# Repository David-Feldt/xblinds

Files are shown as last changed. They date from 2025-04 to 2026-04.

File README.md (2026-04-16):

# xBlinds - Smart Motorized Blinds Controller

An open-source smart blinds controller built on the ESP8266. Control your roller blinds via a web interface, scheduled alarms, rotary encoder, or Home Assistant integration.

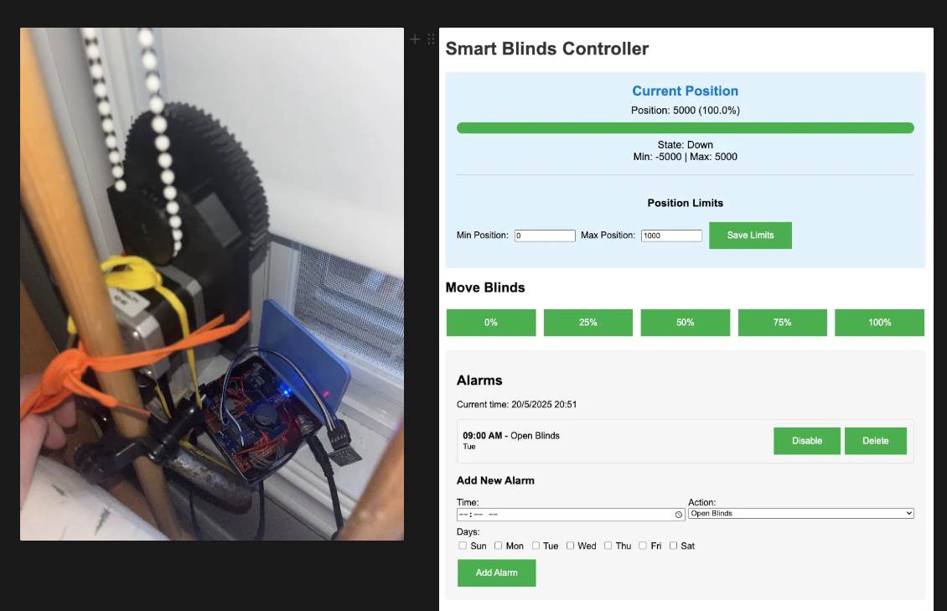
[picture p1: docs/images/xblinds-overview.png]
xBlinds Overview


## Features

- **Web Interface** - Responsive UI with real-time position display, preset buttons (0/25/50/75/100%), and position limit configuration
- **Scheduled Alarms** - Set up to 10 alarms to automatically open or close blinds on specific days and times
- **Rotary Encoder** - Manual control directly on the unit with push-button support
- **NTP Time Sync** - Automatic clock synchronization from the internet
- **WiFi with AP Fallback** - Connects to your home WiFi, falls back to an access point if unavailable
- **mDNS** - Access the controller at `http://blinds.local`
- **EEPROM Persistence** - Saves position, limits, and alarms across reboots
- **ESPHome Support** - Alternative ESPHome configurations for Home Assistant integration

## Hardware

| Component | Description |
|---|---|
| **Microcontroller** | ESP8266 D1 Mini (AZDelivery or similar) |
| **Stepper Motor** | 28BYJ-48 5V with ULN2003 driver board |
| **RTC Module** | DS3231 I2C real-time clock with battery backup |
| **Rotary Encoder** | With push button (KY-040 or similar) |
| **Power Supply** | 5V 2A (do **not** power via USB alone) |

> Alternative: NEMA17 stepper motor with A4988 driver (see `software/nema17/`)

### Wiring

| ESP8266 Pin | Connection |
|---|---|
| D1 | Encoder DT |
| D2 | Encoder CLK |
| D3 | I2C SCL (RTC) |
| D4 | I2C SDA (RTC) |
| D5 | Stepper DIR |
| D6 | Stepper STEP |
| D7 | Encoder Button |

## Getting Started

### 1. Configure WiFi

Edit `software/blinds_controller/blinds_controller.ino` and set your WiFi credentials:

```cpp
const char* ssid = "YOUR_WIFI_SSID";
const char* password = "YOUR_WIFI_PASSWORD";
```

### 2. Build and Upload

Using Arduino CLI:

```bash
# Compile
arduino-cli compile --fqbn esp8266:esp8266:d1_mini software/blinds_controller/blinds_controller.ino

# Upload (adjust port for your system)
arduino-cli upload -p /dev/cu.usbserial-110 --fqbn esp8266:esp8266:d1_mini software/blinds_controller/blinds_controller.ino

# Monitor serial output
arduino-cli monitor -p /dev/cu.usbserial-110 -c baudrate=115200
```

Or use the build script:

```bash
cd software
./build.sh -a  # Build, upload, and monitor
```

### 3. Connect

Once running, the controller is accessible at:
- `http://blinds.local` (via mDNS)
- The IP address shown in the serial monitor

If WiFi connection fails, it creates an open access point with SSID `blinds`.

### 4. Set Position Limits

Use the web UI to configure the min and max positions for your blinds, then save. The controller remembers these across reboots.

## API Endpoints

| Endpoint | Method | Description |
|---|---|---|
| `/` | GET | Web interface |
| `/api/status` | GET | Position, state, limits, network info |
| `/api/moveto?percentage=N` | GET | Move to position (0-100%) |
| `/api/alarms` | GET | List all alarms |
| `/api/alarms` | POST | Add, delete, or toggle alarms |
| `/api/time` | GET/POST | Get or set RTC time |
| `/api/sync-ntp` | GET | Sync clock from NTP |
| `/api/setup?action=X` | GET | Setup mode (start/stop/save/status) |

## ESPHome Alternative

If you prefer ESPHome over custom firmware, configurations are available in:
- `software/blinds.yaml` - Basic ESPHome config
- `esphome/stepper.yaml` - Stepper motor config with Home Assistant integration

## 3D Printed Parts

STL and 3MF files for the enclosure and gears are in the `mechanical/` directory. Designed in FreeCAD.

## Project Structure

```
xblinds/
├── software/
│   ├── blinds_controller/    # Main firmware (recommended)
│   ├── stepper/              # AccelStepper variant
│   ├── nema17/               # NEMA17 motor variant
│   ├── demo_step/            # Basic stepper test
│   ├── blinds.yaml           # ESPHome config
│   └── build.sh              # Build/upload script
├── esphome/                  # ESPHome configurations
├── mechanical/               # 3D models (STL, 3MF, STEP)
└── examples/                 # Reference projects and configs
```

## Dependencies

- [ESP8266 Arduino Core](https://github.com/esp8266/Arduino)
- [RTClib](https://github.com/adafruit/RTClib) - DS3231 RTC support
- [Encoder](https://github.com/PaulStoffregen/Encoder) - Rotary encoder library
- [NTPClient](https://github.com/arduino-libraries/NTPClient) - NTP time sync

## License

This project is open source. Original xBlinds concept from [Thingiverse](https://www.thingiverse.com/thing:4792584).

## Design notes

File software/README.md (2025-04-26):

Compile
arduino-cli compile --fqbn esp8266:esp8266:d1_mini stepper.ino

Upload to ESP8266
arduino-cli upload -p /dev/cu.usbserial-110 --fqbn esp8266:esp8266:d1_mini stepper.ino

Monitor
arduino-cli monitor -p /dev/cu.usbserial-110 -c baudrate=115200

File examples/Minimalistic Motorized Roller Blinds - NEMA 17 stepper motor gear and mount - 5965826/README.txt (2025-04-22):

Minimalistic Motorized Roller Blinds - NEMA 17 stepper motor gear and mount by lushey on Thingiverse: https://www.thingiverse.com/thing:5965826

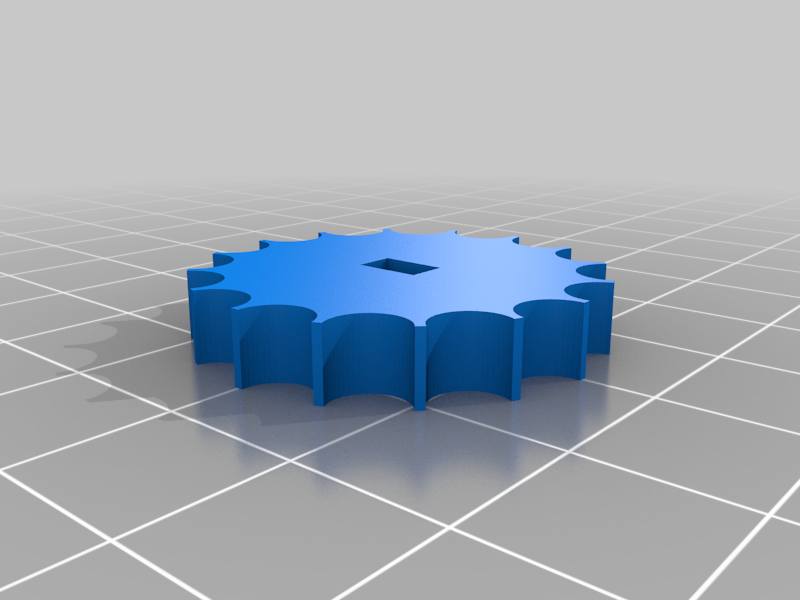
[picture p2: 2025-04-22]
examples/Blinds Smart Home Automation - 4966303/images/Smart_Home_-_Gear.png

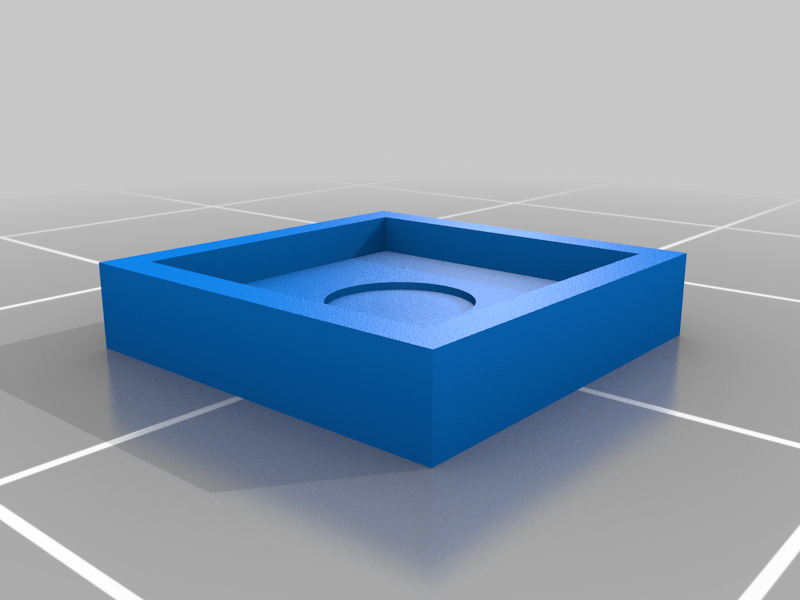
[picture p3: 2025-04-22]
examples/xBlinds - 4792584/images/Tactile_Button_Top.png

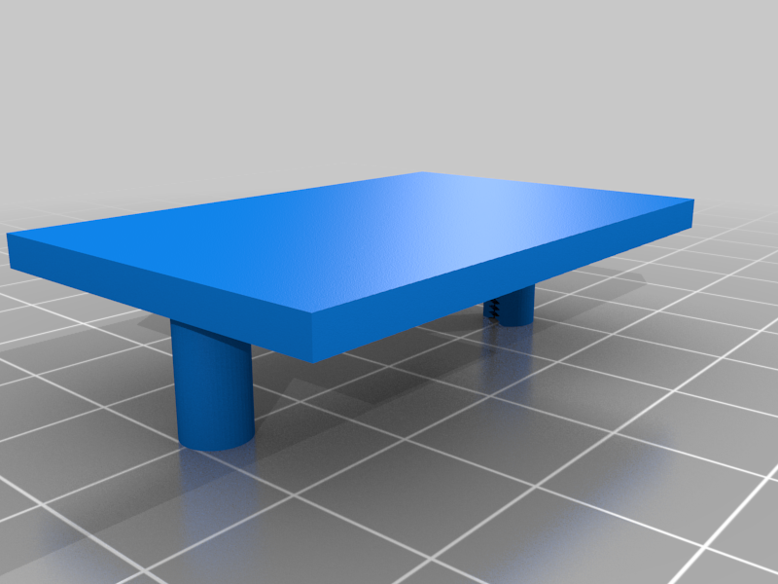
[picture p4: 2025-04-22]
examples/Blinds Smart Home Automation - 4966303/images/Smart_Home_-_Gear_Holder_2-2.png

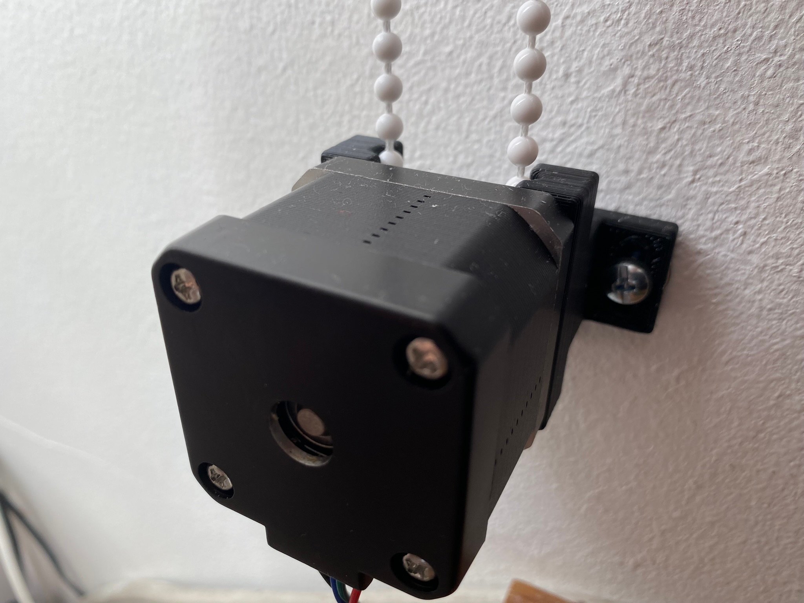
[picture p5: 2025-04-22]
examples/Minimalistic Motorized Roller Blinds - NEMA 17 stepper motor gear and mount - 5965826/images/cdb99ff9-2e51-49e6-be68-403bfa26b47f.JPEG

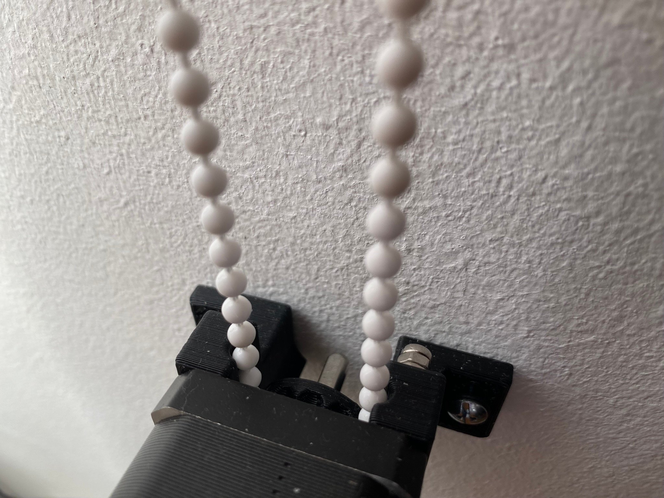
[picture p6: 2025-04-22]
examples/Minimalistic Motorized Roller Blinds - NEMA 17 stepper motor gear and mount - 5965826/images/24057941-1a3e-4d87-ac36-347bbf882cc1.JPEG

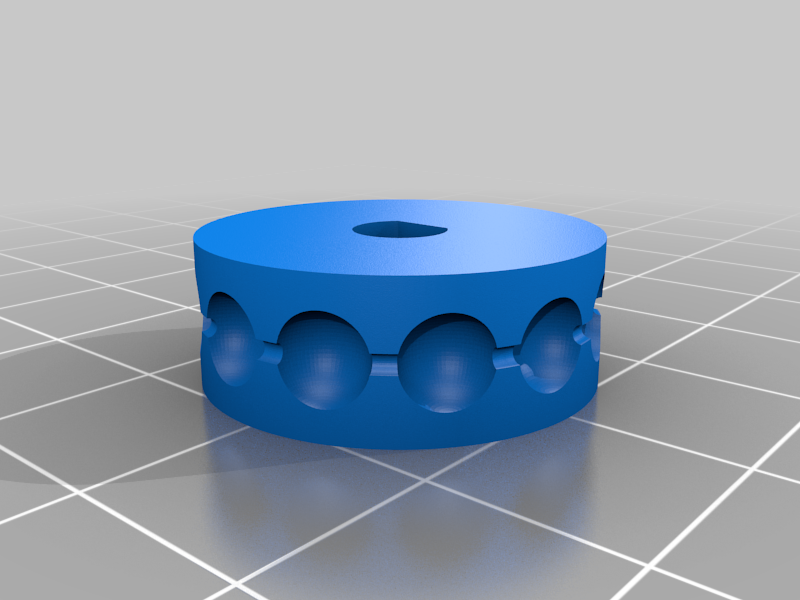
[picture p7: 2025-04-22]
examples/Minimalistic Motorized Roller Blinds - NEMA 17 stepper motor gear and mount - 5965826/images/0aa5c6c5-0e26-4882-9368-393df4448d87.png

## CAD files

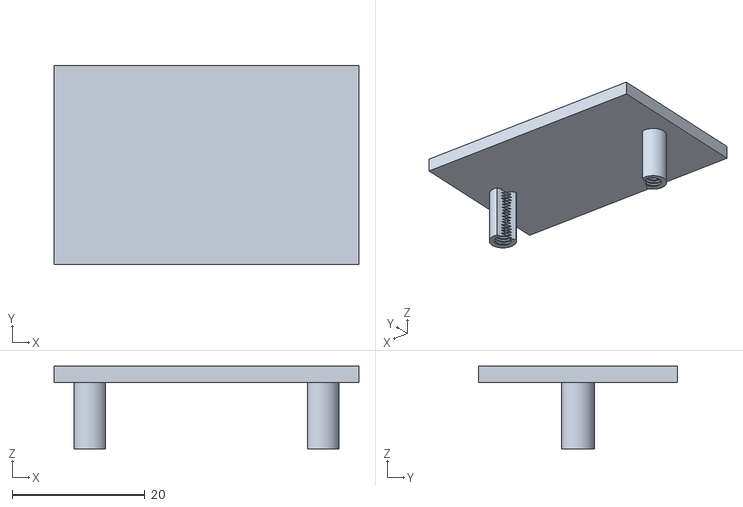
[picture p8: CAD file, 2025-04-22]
examples/Blinds Smart Home Automation - 4966303/files/Smart_Home_-_Gear_Holder_2-2.stl
46.0 x 30.0 x 12.5

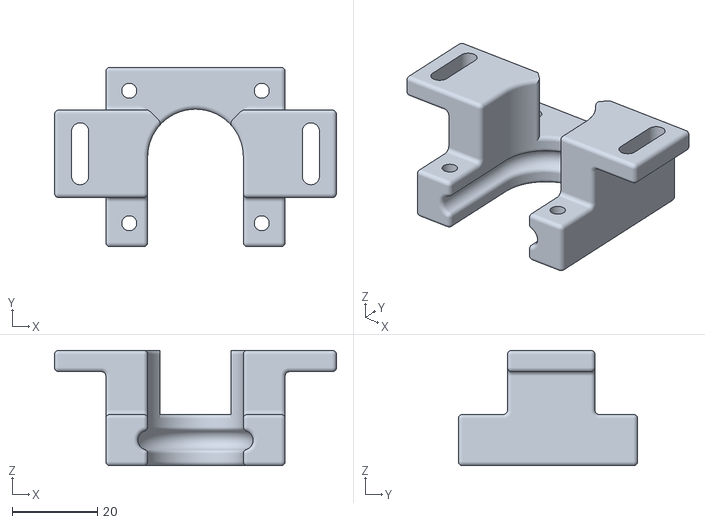
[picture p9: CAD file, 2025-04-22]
examples/Minimalistic Motorized Roller Blinds - NEMA 17 stepper motor gear and mount - 5965826/files/roller_blinds_stepper_mount_v4_roller_blinds_stepper_mount_v4_bracket.stl
66.0 x 42.0 x 27.0

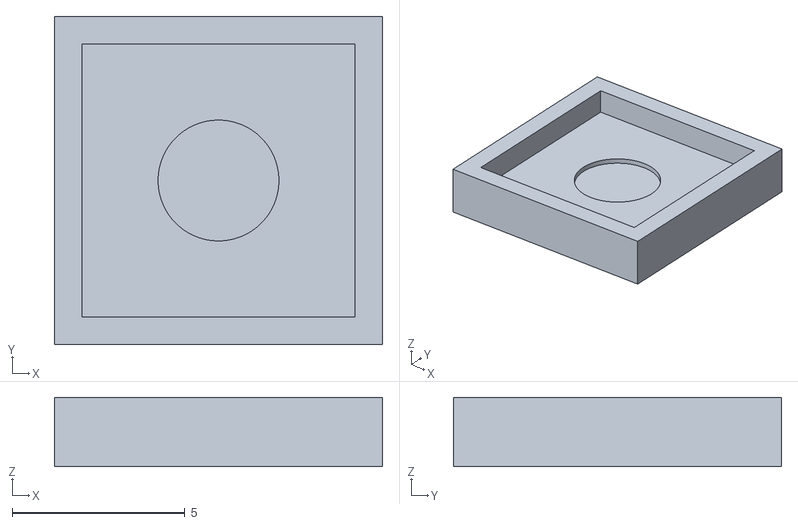
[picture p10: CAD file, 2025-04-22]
examples/xBlinds - 4792584/files/Tactile_Button_Top.stl
9.50 x 9.50 x 2.00

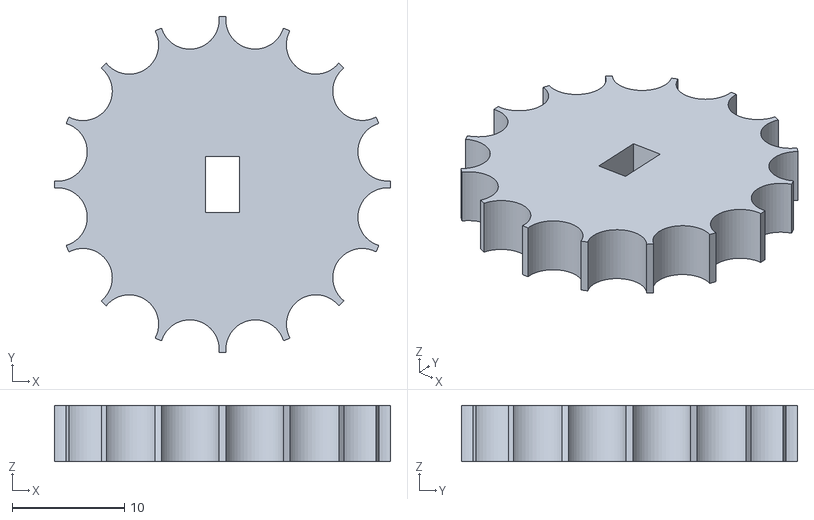
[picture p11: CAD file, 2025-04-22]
examples/Blinds Smart Home Automation - 4966303/files/Smart_Home_-_Gear.stl
30.0 x 30.0 x 5.00

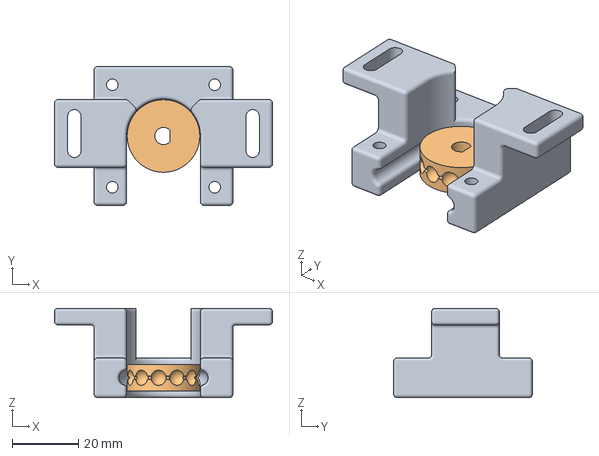
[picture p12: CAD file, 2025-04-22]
examples/Minimalistic Motorized Roller Blinds - NEMA 17 stepper motor gear and mount - 5965826/files/roller_blinds_stepper_mount_v4.3mf
66.0 x 42.0 x 27.0 mm
bracket
gear

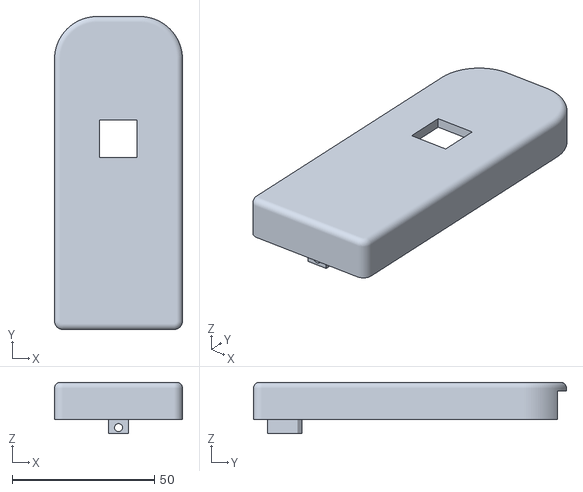
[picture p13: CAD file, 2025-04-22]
examples/xBlinds - 4792584/files/BoxTop-ButtonHole.stl
45.0 x 110.0 x 18.0

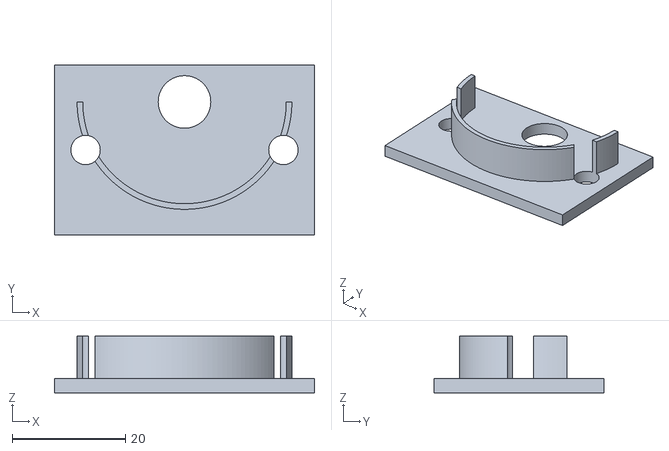
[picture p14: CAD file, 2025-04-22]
examples/Blinds Smart Home Automation - 4966303/files/Smart_Home_-_Gear_Holder_1-2.stl
46.0 x 30.0 x 10.0

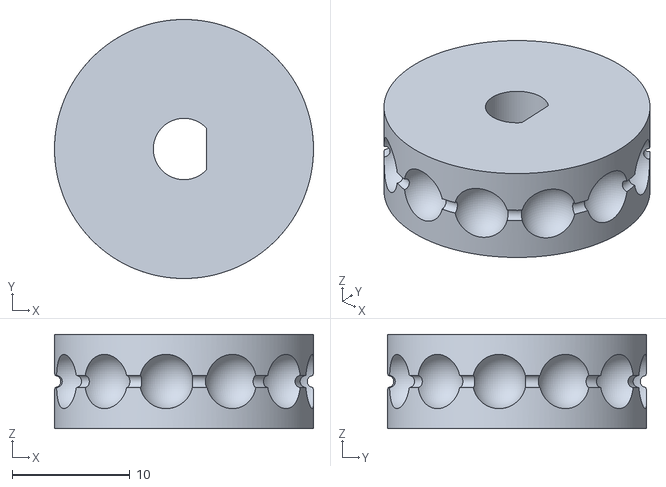
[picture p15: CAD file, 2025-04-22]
examples/Minimalistic Motorized Roller Blinds - NEMA 17 stepper motor gear and mount - 5965826/files/roller_blinds_stepper_mount_v4_roller_blinds_stepper_mount_v4_gear.stl
22.0 x 22.0 x 8.00

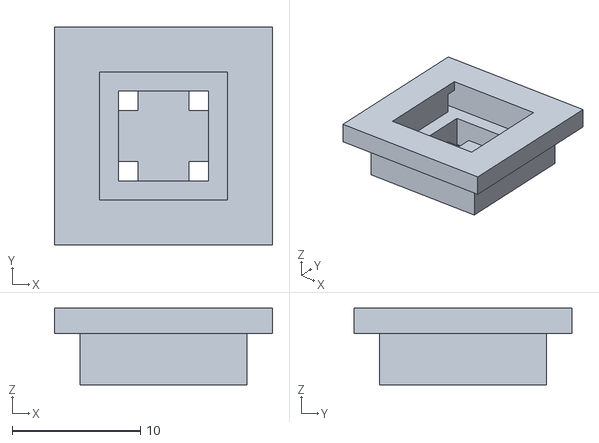
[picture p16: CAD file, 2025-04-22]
examples/xBlinds - 4792584/files/Tactile_Button_Base_Square.stl
17.0 x 17.0 x 6.00

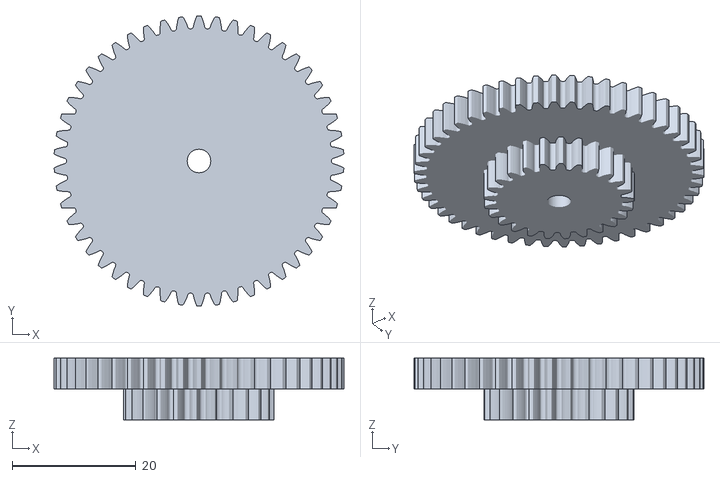
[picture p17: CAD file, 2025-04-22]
mechanical/gear2.1.stl
46.7 x 46.8 x 10.0

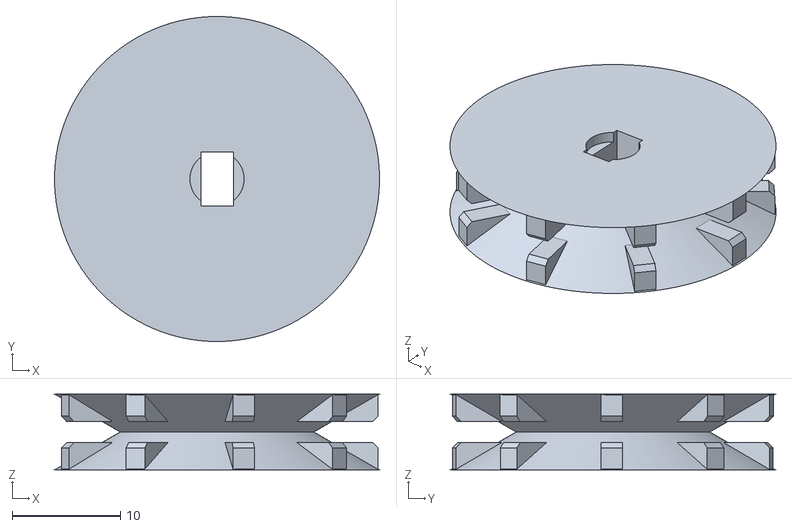
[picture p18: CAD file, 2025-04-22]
examples/xBlinds - 4792584/files/Pulley-40deg.stl
30.0 x 30.0 x 7.00

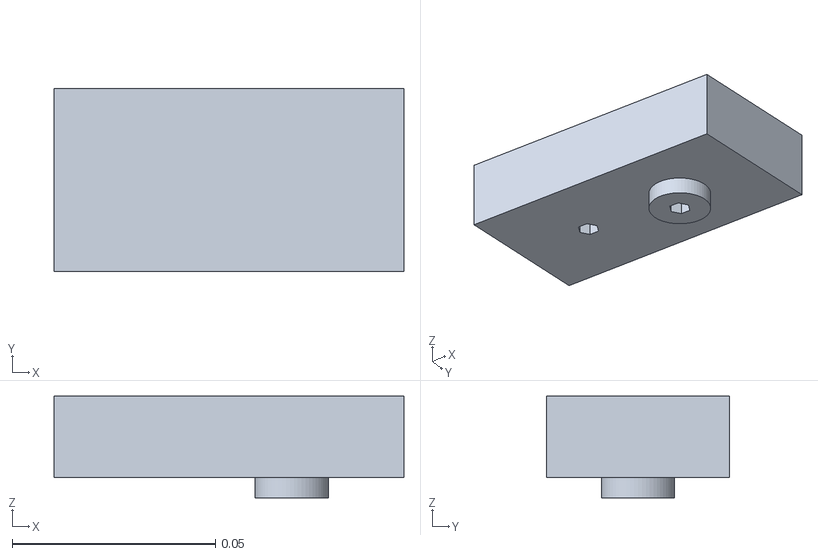
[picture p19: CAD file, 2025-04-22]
mechanical/Gear Base.stl
0.0861 x 0.045 x 0.025

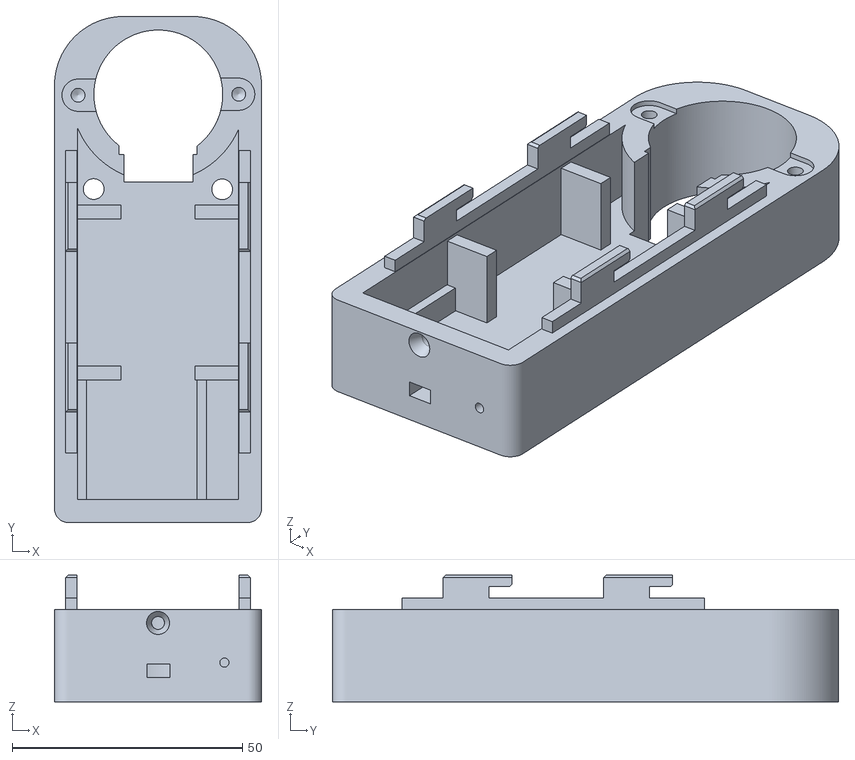
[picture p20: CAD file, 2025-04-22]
examples/xBlinds - 4792584/files/BoxBottom.stl
45.0 x 110.0 x 27.5

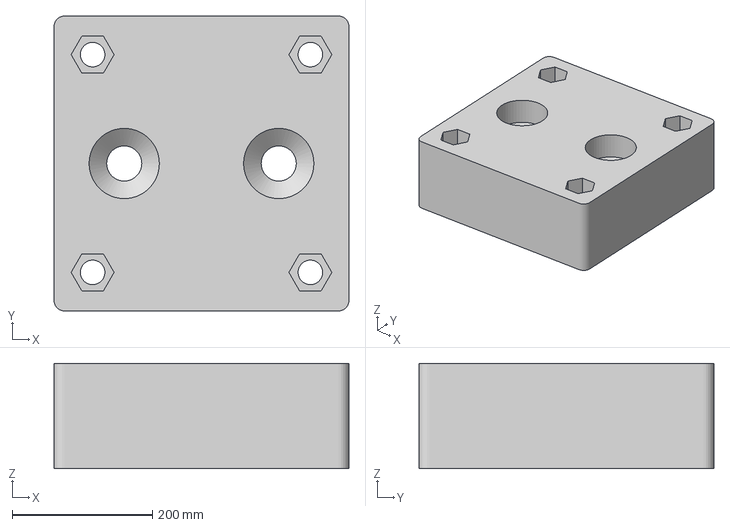
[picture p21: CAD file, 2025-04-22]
mechanical/xblinds-attacheed v1.3mf
420.0 x 420.0 x 150.0 mm

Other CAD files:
mechanical/mounted_step.3mf
examples/xBlinds - 4792584/files/BoxTop.stl
examples/xBlinds - 4792584/files/Tactile_Button_Base_Rounded.stl
mechanical/xblinds v5.3mf
examples/Minimalistic Motorized Roller Blinds - NEMA 17 stepper motor gear and mount - 5965826/files/roller_blinds_stepper_mount_v4.f3d
examples/xBlinds - 4792584/files/Pulley-40deg.f3d
mechanical/Gear 1.stl
mechanical/Gear 2.stl
mechanical/blinds_holder.stl
mechanical/gear3.1.stl
mechanical/gear3.stl
mechanical/xblinds v1.3mf
mechanical/xblinds v1.stl
mechanical/xblinds v3.3mf
mechanical/xblinds v4.3mf
mechanical/xblinds-attacheed v1.stl

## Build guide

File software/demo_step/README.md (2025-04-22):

# xBlinds

The xBlinds project started because I wanted a (cheap) way to motorize my vertical blinds and existing commercial solutions are heavily priced and not getting the best reviews, so a wintery night I started sketching the UI in Notepad.

This project is two-fold; the bin and guide published here and the STL for the casing on Thingiverse https://www.thingiverse.com/thing:4792584.

2022.04.15:
xBlinds is now feature complete (for my use, at least) and I've released the v1.0 bin and source code - please find all releases and release notes in the right side of your browser.
There is important information among the release notes not documented in the README.md so make sure you read through them all!

## Quick Guide

The bin is compiled for ESP8266 and will run on most variants but most importantly on the D1 mini which will fit into the 3D-printed casing.

Use your favorite flasher to flash the ESP (plenty of guides available for that out there).

## Caution

> If your blinds aren't running smoothly you may damage the stepper or the blinds when trying to pull the beaded string. I had to lube the gears in one of my blinds with some WD-40 for it to run smooth enough for the stepper to pull it. You may want to print the pulley first and just try it with the stepper handheld, to avoid any damage.
> The stepper is configured for max torque using the FULL4WIRE mode of the AccelStepper library in combination with slow acceleration.

### Initial Setup

When powering up the ESP for the first time, it will show up as a WiFi AP with the SSID xblinds-abcdef (where "abcdef" are the last 6 digits of the MAC address), use the password "persienne" (Venetian blind in Danish) to log on to the SSID.

To access the web based setup, enter the address 4.3.2.1 which will take you to the main screen (described later).

In the bottom of the screen, press WiFi to open this screen:

WiFisetup

Hostname can't be edited, it will always be xblinds-abcdef (defined by MAC address).

Input your home SSID and password and press save.

Once connected to your home WiFi, the ESP will no longer publish an AP so you need to find its new IP address in your router.

If at all possible, make sure the SSID you're using is 2.4GHz only, as the ESPs can show random errors and/or disconnects when using shared 2.4/5GHz SSIDs. This is also the case if you have channel interference from neighbors, etc.

### Adjusting the Blinds

I've put in some default stepper values in the code, they will most likely not fit your usage (or mine, for that matter), they are simply there to test that the stepper moves, when buttons are pressed.

Setup

My recommendation is to attach to the blinds when they're closed and then press "Save as Closed" when the beaded line is seated well and the vertical blinds are closed.

> Note!
> Pressing + will turn the pulley counter-clockwise. Be careful you don't overstretch the line and/or break the gears in the stepper or the blinds.

Adjust your blinds, pressing + and - and press "Save as Normal Open" or "Save as Full Open" when they are in the desired position. A "half" position is calculated behind the scenes. Allow a couple of seconds between each press.

If you want to save your own half position, v0.4 added the "Override Half Open" button to do just that and the "Reset Half" button to revert to the calculated position.

To be able to use tilt, which is introduced in v0.8, you need to at least define the "closed" and "full" presets, as they will be used as 0 and 100 percent open.

You can test your positions on the main screen:

Main

The positions may need some tweaking after the strings have settled in. And you may need to adjust the positions after firmware updates.

### MQTT

My main objective with this project was to have Home Assistant take care of the blinds, instead of me fiddling with my phone to open and close them, which is why I added MQTT to the mix. If you have no need for MQTT, leave this page blank - you may see untested results, if you put in a non-existing server, just saying...

MQTT

The default group is xblinds/all but you can name it whatever you want. I'm using xblinds/window for my three xblinds working together.

Input your MQTT server IP address. I'm using Mosquitto on Home Assistant, but I guess you could use CloudMQTT or a similar service, if you want.

Default MQTT port is 1883.

Lastly input a username and password for an account that has write access, as xblinds publishes a status.

If you experience unexpected open/closing of your blinds, you may have some lingering MQTT retained messages in the queue. I can recommend using MQTT Explorer (http://mqtt-explorer.com/) for troubleshooting and clearing of those messages.

### Home Assistant Yaml

Use this configuration to have your xBlinds using Home Assistant's "Cover" integration. See https://www.home-assistant.io/integrations/cover.mqtt/ and note that v0.8 has added support for "tilt". Note: Syntax has changed in Home Assistant 2022.7
```yaml
mqtt:
  cover:
    - name: "xBlinds Window"
      command_topic: "xblinds/window"
      state_topic: "xblinds/window/status"
      qos: 0
      retain: true
      payload_open: "open"
      payload_close: "close"
      state_open: "open"
      state_closed: "closed"
      optimistic: false
      tilt_command_topic: "xblinds/window/tilt"
      tilt_status_topic: "xblinds/window/tilt-state"
      tilt_optimistic: false
```

You can also use MQTT directly in your automations/scripts:

```yaml
scene_shades_open:
  alias: Shades Open
  sequence:
    - service: mqtt.publish
      data:
        topic: xblinds/window
        retain: true
        payload: open
```

Or address the tilt as presets, like this:

```yaml
scene_shades_open:
  alias: Shades Open 80%
  sequence:
    - service: mqtt.publish
      data:
        topic: xblinds/window/tilt
        retain: true
        payload: 80
```

The recognized payload keywords are:
- close
- open
- half
- full

The returned status messages are (changed in v0.7):
- closing
- closed
- opening
- open
- "hostname" is not connected
- Reconnected
- Rebooted

### OTA Update

I realized that updating the firmware would be a hassle, if you'd already mounted the unit somewhere more or less accessible, so version 0.4 added OTA support, just navigate to http://IP-address/update to upload and update to newer versions of the firmware.

### Toogle button

Version 0.5 adds support for a tactile button to toggle open/close directly on the xBlinds unit. It will require printing a new lid (available on Thingiverse) for the unit and it's completely optional.

### Thingiverse

If you want to 3D print this project, go to Thingiverse to download the STLs here: https://www.thingiverse.com/thing:4792584

Here's the xblinds unit assembled: (You can safely desolder the LED's on the ULN2003 stepper driver if you should want to).

3D-print

And this is what it looks like mounted on the wall:

Mounted

### Bill of Materials

#### Steppers and drivers:
ANGEEK 5 pcs. 5V 28BYJ-48 ULN2003 Stepper Motor with Drive Module Board

* Amazon affiliate link: https://amzn.to/4bvPhqd

#### D1 mini:
AZDelivery D1 Mini NodeMcu with ESP8266-12F WLAN Module

> Note!
> Different manufacturers have different dimensions.

* Amazon affiliate link: https://amzn.to/49CFDQR
* AZDelivery: https://www.az-delivery.de/products/d1-mini

#### Tactile Button:
Tactile Push Button Switch 6x6x4.3 (6x6x5 should be fine as well)<br/>
10 kOhm pull-down resistor

* Amazon affiliate link: https://amzn.to/49eNN1K

#### Power supply:
Any 5V PSU will do, I've calculated ~2A per unit to be on the safe side.<br/>
**Do not use USB to power the D1 and stepper, the 5V pin will not deliver sufficient current to drive the stepper**

### Wiring diagram

Wiring

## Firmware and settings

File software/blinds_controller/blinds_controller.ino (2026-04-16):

#include <Wire.h>
#include <RTClib.h>
#include <Encoder.h>
#include <EEPROM.h>
#include <ESP8266WiFi.h>
#include <ESP8266WebServer.h>
#include <ESP8266mDNS.h>
#include <ESP8266HTTPClient.h>
#include <NTPClient.h>
#include <WiFiUdp.h>

// Add watchdog timer
#include <ESP8266WiFiMulti.h>
ESP8266WiFiMulti wifiMulti;

// Server health check variables
unsigned long lastServerCheck = 0;
const unsigned long SERVER_CHECK_INTERVAL = 30000; // Check every 30 seconds
bool serverRunning = false;
int serverRestartCount = 0;
const int MAX_RESTARTS = 5;
const unsigned long RESTART_COOLDOWN = 300000; // 5 minutes between restart attempts
unsigned long lastRestartAttempt = 0;

// Pin Definitions
#define DIR_PIN D5      // Direction pin for stepper motor
#define STEP_PIN D6     // Step pin for stepper motor
#define SDA_PIN D4      // I2C SDA pin for RTC
#define SCL_PIN D3      // I2C SCL pin for RTC
#define ENCODER_CLK D2  // Encoder clock pin
#define ENCODER_DT D1   // Encoder data pin
#define ENCODER_BTN D7  // Encoder button pin

// Motor settings
#define STEPS_PER_REVOLUTION 200
#define MICROSTEPS 1  // Full steps for maximum torque
#define MAX_SPEED 8000          // Even slower maximum speed for maximum torque
#define MIN_SPEED 12000         // Even slower minimum speed for maximum torque
#define STEP_DELAY 1000         // Much longer base delay between steps for maximum torque
#define ENCODER_MULTIPLIER 200   // How many steps per encoder click

// EEPROM addresses
#define EEPROM_SIZE 512
#define MIN_POS_ADDR 0
#define MAX_POS_ADDR 4
#define CURRENT_POS_ADDR 8
#define ALARM_COUNT_ADDR 12
#define ALARM_DATA_START 16     // Each alarm takes 5 bytes (hour, minute, action, enabled, days)

// Blind states
#define BLIND_UP 0
#define BLIND_DOWN 1
#define BLIND_CUSTOM 2

// WiFi settings - UPDATE THESE WITH YOUR NETWORK CREDENTIALS
const char* ssid = "YOUR_WIFI_SSID";
const char* password = "YOUR_WIFI_PASSWORD";

// Global objects
RTC_DS3231 rtc;
Encoder myEncoder(ENCODER_CLK, ENCODER_DT);
ESP8266WebServer server(80);

// Global variables
long currentPosition = 0;
long minPosition = 0;
long maxPosition = 1000;
int blindState = BLIND_UP;
bool setupMode = false;
bool btnPressed = false;
unsigned long lastEncoderMove = 0;
unsigned long lastBtnCheck = 0;
unsigned long lastTimeCheck = 0;

// Add these global variables after other global variables
unsigned long lastStepTime = 0;
bool isMoving = false;
long targetPosition = 0;
int stepDelay = 1000; // Default step delay in microseconds

// Add after other global variables
bool isConnected = true;

// Alarm structure
struct Alarm {
  uint8_t hour;
  uint8_t minute;
  uint8_t action; // 0 = up, 1 = down
  bool enabled;
  uint8_t days; // Bit field for days (0 = Sunday, 1 = Monday, etc.)
};

#define MAX_ALARMS 10
Alarm alarms[MAX_ALARMS];
int alarmCount = 0;

// Add these global variables
bool webSetupMode = false;
long setupMinPosition = 0;
long setupMaxPosition = 1000;

// Add after other global variables
bool isAPMode = false;
const char* AP_SSID = "blinds";
const char* AP_PASSWORD = ""; // You can change this password

WiFiUDP ntpUDP;
NTPClient timeClient(ntpUDP, "pool.ntp.org", -14400, 60000); // EDT timezone (-4 hours)

void setup() {
  // Initialize serial for debugging
  Serial.begin(115200);
  delay(1000);
  Serial.println("\nSmart Blinds Controller Starting...");
  
  // Initialize EEPROM
  EEPROM.begin(EEPROM_SIZE);
  
  // Initialize I2C for RTC
  Wire.begin(SDA_PIN, SCL_PIN);
  
  // Initialize RTC
  if (!rtc.begin()) {
    Serial.println("Couldn't find RTC");
    while (1);
  }

  // If RTC lost power, set the time
  if (rtc.lostPower()) {
    Serial.println("RTC lost power, setting the time!");
    rtc.adjust(DateTime(F(__DATE__), F(__TIME__)));
  }
  
  // Set pin modes
  pinMode(STEP_PIN, OUTPUT);
  pinMode(DIR_PIN, OUTPUT);
  pinMode(ENCODER_BTN, INPUT_PULLUP);
  
  // Load saved values from EEPROM
  loadSettingsFromEEPROM();
  
  // Initialize WiFi with multiple networks
  wifiMulti.addAP(ssid, password);
  // Add backup network if available
  // wifiMulti.addAP("backup_ssid", "backup_password");
  
  Serial.print("Connecting to WiFi");
  
  int attempts = 0;
  while (wifiMulti.run() != WL_CONNECTED && attempts < 20) {
    delay(500);
    Serial.print(".");
    attempts++;
  }
  
  if (wifiMulti.run() == WL_CONNECTED) {
    Serial.println("\nWiFi connected");
    Serial.print("IP address: ");
    Serial.println(WiFi.localIP());
    isAPMode = false;
    
    // Sync time from NTP on boot
    syncTimeFromNTP();
  } else {
    Serial.println("\nWiFi connection failed, starting Access Point mode");
    startAccessPoint();
  }
  
  // Initialize mDNS
  if (MDNS.begin("blinds")) {
    Serial.println("mDNS responder started");
    Serial.println("You can now access the device at http://blinds.local");
    
    // Add service to mDNS
    MDNS.addService("http", "tcp", 80);
  } else {
    Serial.println("Error setting up mDNS responder!");
  }
  
  // Setup web server routes
  setupWebServer();
  serverRunning = true;
  
  // Check if button is pressed during startup for setup mode
  if (digitalRead(ENCODER_BTN) == LOW) {
    Serial.println("Button pressed at startup - entering setup mode");
    delay(2000); // Wait to ensure it's a deliberate press
    if (digitalRead(ENCODER_BTN) == LOW) {
      enterSetupMode();
    }
  }
  
  Serial.println("System Ready");
}

void loop() {
  // Handle mDNS updates
  MDNS.update();
  
  // Check server health
  checkServerHealth();
  
  // Handle web server requests
  server.handleClient();
  
  // Update motor position
  updateMotor();
  
  // Check encoder for manual control
  checkEncoder();
  
  // Check button presses
  checkButton();
  
  // Check if any alarms need to be triggered
  if (millis() - lastTimeCheck > 30000) {
    checkAlarms();
    lastTimeCheck = millis();
  }
  
  // Handle setup mode if active
  if (setupMode) {
    handleSetupMode();
  }
  
  // Yield to prevent watchdog timer issues
  yield();
}

void checkServerHealth() {
  if (millis() - lastServerCheck >= SERVER_CHECK_INTERVAL) {
    lastServerCheck = millis();
    
    // Try to make a request to the server
    HTTPClient http;
    WiFiClient client;
    String url = "http://" + WiFi.localIP().toString() + "/api/status";
    if (http.begin(client, url)) {
      int httpCode = http.GET();
      http.end();
      
      if (httpCode != 200) {
        Serial.println("Server health check failed. HTTP code: " + String(httpCode));
        serverRunning = false;
        
        // Check if we should attempt a restart
        if (serverRestartCount < MAX_RESTARTS && 
            (millis() - lastRestartAttempt) > RESTART_COOLDOWN) {
          restartServer();
        }
      } else {
        serverRunning = true;
        // Reset restart count if server is healthy
        serverRestartCount = 0;
      }
    } else {
      Serial.println("Failed to begin HTTP request");
      serverRunning = false;
    }
  }
}

void restartServer() {
  Serial.println("Attempting to restart server...");
  lastRestartAttempt = millis();
  serverRestartCount++;
  
  // Stop the current server
  server.stop();
  delay(1000);
  
  // Reinitialize WiFi if needed
  if (!isAPMode) {
    if (wifiMulti.run() != WL_CONNECTED) {
      Serial.println("Reconnecting to WiFi...");
      int attempts = 0;
      while (wifiMulti.run() != WL_CONNECTED && attempts < 20) {
        delay(500);
        Serial.print(".");
        attempts++;
      }
      
      // If still not connected, switch to AP mode
      if (wifiMulti.run() != WL_CONNECTED) {
        Serial.println("WiFi connection failed, switching to Access Point mode");
        startAccessPoint();
      }
    }
  }
  
  // Restart mDNS
  MDNS.end();
  if (MDNS.begin("blinds")) {
    MDNS.addService("http", "tcp", 80);
  }
  
  // Restart the server
  setupWebServer();
  server.begin();
  serverRunning = true;
  
  Serial.println("Server restart completed. Attempt " + String(serverRestartCount) + " of " + String(MAX_RESTARTS));
}

// Add a function to handle server errors
void handleServerError() {
  if (!serverRunning) {
    Serial.println("Server error detected, attempting recovery...");
    restartServer();
  }
}

void loadSettingsFromEEPROM() {
  // Read min and max positions
  EEPROM.get(MIN_POS_ADDR, minPosition);
  EEPROM.get(MAX_POS_ADDR, maxPosition);
  EEPROM.get(CURRENT_POS_ADDR, currentPosition);
  
  // Read alarm count
  EEPROM.get(ALARM_COUNT_ADDR, alarmCount);
  
  // Sanity check on loaded values
  if (alarmCount < 0 || alarmCount > MAX_ALARMS) {
    alarmCount = 0;
  }
  
  if (minPosition > maxPosition || minPosition < -10000 || maxPosition > 10000) {
    // Default values if EEPROM has invalid data
    minPosition = 0;
    maxPosition = 1000;
    currentPosition = 0;
  }
  
  // Load all alarms
  for (int i = 0; i < alarmCount; i++) {
    int addr = ALARM_DATA_START + (i * 5); // 5 bytes per alarm
    alarms[i].hour = EEPROM.read(addr);
    alarms[i].minute = EEPROM.read(addr + 1);
    alarms[i].action = EEPROM.read(addr + 2);
    alarms[i].enabled = EEPROM.read(addr + 3) == 1;
    alarms[i].days = EEPROM.read(addr + 4);
    
    // Validate values
    if (alarms[i].hour > 23 || alarms[i].minute > 59 || alarms[i].action > 1) {
      // Invalid alarm data, disable it
      alarms[i].enabled = false;
    }
  }
  
  // Initialize encoder with current position (at 1/ENCODER_MULTIPLIER scale)
  myEncoder.write(currentPosition / ENCODER_MULTIPLIER);
  
  Serial.println("Settings loaded from EEPROM:");
  Serial.print("Min Position: ");
  Serial.println(minPosition);
  Serial.print("Max Position: ");
  Serial.println(maxPosition);
  Serial.print("Current Position: ");
  Serial.println(currentPosition);
  Serial.print("Encoder Position: ");
  Serial.println(currentPosition / ENCODER_MULTIPLIER);
  Serial.print("Alarm Count: ");
  Serial.println(alarmCount);
}

void saveSettingsToEEPROM() {
  EEPROM.put(MIN_POS_ADDR, minPosition);
  EEPROM.put(MAX_POS_ADDR, maxPosition);
  EEPROM.put(CURRENT_POS_ADDR, currentPosition);
  EEPROM.put(ALARM_COUNT_ADDR, alarmCount);
  
  // Save all alarms
  for (int i = 0; i < alarmCount; i++) {
    int addr = ALARM_DATA_START + (i * 5); // 5 bytes per alarm (hour, minute, action, enabled, days)
    EEPROM.write(addr, alarms[i].hour);
    EEPROM.write(addr + 1, alarms[i].minute);
    EEPROM.write(addr + 2, alarms[i].action);
    EEPROM.write(addr + 3, alarms[i].enabled ? 1 : 0);
    EEPROM.write(addr + 4, alarms[i].days);
  }
  
  EEPROM.commit();
  Serial.println("Settings saved to EEPROM");
}

void checkEncoder() {
  long encoderPosition = myEncoder.read();
  long expectedEncoderPosition = currentPosition / ENCODER_MULTIPLIER;
  
  // If encoder position doesn't match expected position
  if (encoderPosition != expectedEncoderPosition) {
    lastEncoderMove = millis();
    
    // Calculate the difference in encoder clicks
    long encoderDifference = encoderPosition - expectedEncoderPosition;
    
    // Calculate the new target position
    long newTargetPosition = currentPosition + (encoderDifference * ENCODER_MULTIPLIER);
    
    // Limit position to min/max
    if (newTargetPosition < minPosition) {
      newTargetPosition = minPosition;
      // Update encoder to match the min position
      myEncoder.write(minPosition / ENCODER_MULTIPLIER);
    }
    if (newTargetPosition > maxPosition) {
      newTargetPosition = maxPosition;
      // Update encoder to match the max position
      myEncoder.write(maxPosition / ENCODER_MULTIPLIER);
    }
    
    // If position has really changed after limits
    if (newTargetPosition != currentPosition) {
      Serial.print("Encoder moved. Current: ");
      Serial.print(currentPosition);
      Serial.print(", Target: ");
      Serial.println(newTargetPosition);
      
      moveBlindToPosition(newTargetPosition);
      
      // Save current position to EEPROM
      EEPROM.put(CURRENT_POS_ADDR, currentPosition);
      EEPROM.commit();
      
      // Update blind state
      if (currentPosition == minPosition) {
        blindState = BLIND_UP;
      } else if (currentPosition == maxPosition) {
        blindState = BLIND_DOWN;
      } else {
        blindState = BLIND_CUSTOM;
      }
    }
  }
}

void checkButton() {
  // Debounce button
  if (millis() - lastBtnCheck < 50) return;
  lastBtnCheck = millis();
  
  bool currentBtnState = digitalRead(ENCODER_BTN) == LOW;
  
  if (currentBtnState && !btnPressed) {
    btnPressed = true;
    Serial.println("Button pressed");
    
    // If not in setup mode, toggle between up and down
    if (!setupMode) {
      if (blindState == BLIND_UP) {
        moveBlindDown();
      } else {
        moveBlindUp();
      }
    }
  } else if (!currentBtnState && btnPressed) {
    btnPressed = false;
    Serial.println("Button released");
  }
}

void moveBlindToPosition(long newTargetPosition) {
  targetPosition = newTargetPosition;
  isMoving = true;
  
  // Set direction
  bool direction = targetPosition > currentPosition;
  digitalWrite(DIR_PIN, direction ? HIGH : LOW);
  
  // Set initial speed
  stepDelay = MAX_SPEED;
  
  // Small delay to ensure direction is set
  delayMicroseconds(100);
}

void updateMotor() {
  if (!isMoving) return;
  
  unsigned long currentTime = micros();
  
  // Check if it's time for the next step
  if (currentTime - lastStepTime >= stepDelay) {
    lastStepTime = currentTime;
    
    // Take a single step with proper timing
    digitalWrite(STEP_PIN, HIGH);
    delayMicroseconds(STEP_DELAY);  // Much longer delay for maximum torque
    digitalWrite(STEP_PIN, LOW);
    
    // Update position
    if (targetPosition > currentPosition) {
      currentPosition++;
    } else if (targetPosition < currentPosition) {
      currentPosition--;
    }
    
    // Update encoder position to match motor position (at 1/ENCODER_MULTIPLIER scale)
    myEncoder.write(currentPosition / ENCODER_MULTIPLIER);
    
    // Debug output for motor movement
    if (currentPosition % 100 == 0) {  // Print every 100 steps
      Serial.print("Motor position: ");
      Serial.print(currentPosition);
      Serial.print(", Target: ");
      Serial.print(targetPosition);
      Serial.print(", Steps remaining: ");
      Serial.println(abs(targetPosition - currentPosition));
    }
    
    // Check if we've reached the target
    if (currentPosition == targetPosition) {
      isMoving = false;
      // Save current position to EEPROM
      EEPROM.put(CURRENT_POS_ADDR, currentPosition);
      EEPROM.commit();
      
      // Update blind state
      if (currentPosition == minPosition) {
        blindState = BLIND_UP;
      } else if (currentPosition == maxPosition) {
        blindState = BLIND_DOWN;
      } else {
        blindState = BLIND_CUSTOM;
      }
    }
    
    // Speed control with very gradual acceleration/deceleration
    if (isMoving) {
      long stepsRemaining = abs(targetPosition - currentPosition);
      if (stepsRemaining > 500) {  // Much longer acceleration zone
        stepDelay = MAX_SPEED;
      } else if (stepsRemaining < 200) {  // Much longer deceleration zone
        stepDelay = MIN_SPEED;
      } else {
        // Linear interpolation between MAX_SPEED and MIN_SPEED
        stepDelay = MAX_SPEED + ((MIN_SPEED - MAX_SPEED) * (500 - stepsRemaining) / 300);
      }
    }
  }
}

void moveBlindUp() {
  Serial.println("Moving blind up");
  moveBlindToPosition(minPosition);
}

void moveBlindDown() {
  Serial.println("Moving blind down");
  moveBlindToPosition(maxPosition);
}

void enterSetupMode() {
  setupMode = true;
  Serial.println("Entering setup mode");
  Serial.println("Use encoder to set MIN position, then press button");
  
  // Reset encoder
  currentPosition = 0;
  myEncoder.write(0);
}

void handleSetupMode() {
  if (server.hasArg("action")) {
    String action = server.arg("action");
    
    if (action == "start") {
      webSetupMode = true;
      setupMinPosition = minPosition;
      setupMaxPosition = maxPosition;
      server.send(200, "text/plain", "Setup mode started");
    } 
    else if (action == "stop") {
      webSetupMode = false;
      server.send(200, "text/plain", "Setup mode stopped");
    }
    else if (action == "save") {
      if (server.hasArg("min") && server.hasArg("max")) {
        setupMinPosition = server.arg("min").toInt();
        setupMaxPosition = server.arg("max").toInt();
        
        // Validate values
        if (setupMinPosition >= setupMaxPosition) {
          server.send(400, "text/plain", "Invalid values: min must be less than max");
          return;
        }
        
        // Save to EEPROM
        minPosition = setupMinPosition;
        maxPosition = setupMaxPosition;
        EEPROM.put(MIN_POS_ADDR, minPosition);
        EEPROM.put(MAX_POS_ADDR, maxPosition);
        EEPROM.commit();
        
        webSetupMode = false;
        server.send(200, "text/plain", "Settings saved");
      } else {
        server.send(400, "text/plain", "Missing parameters");
      }
    }
    else if (action == "status") {
      String json = "{";
      json += "\"setupMode\":" + String(webSetupMode ? "true" : "false") + ",";
      json += "\"minPosition\":" + String(setupMinPosition) + ",";
      json += "\"maxPosition\":" + String(setupMaxPosition);
      json += "}";
      server.send(200, "application/json", json);
    }
  } else {
    server.send(400, "text/plain", "Missing action parameter");
  }
}

void moveStepperBySteps(long steps) {
  // Set direction
  bool direction = steps > 0;
  digitalWrite(DIR_PIN, direction ? HIGH : LOW);
  
  // Calculate absolute steps
  long absSteps = abs(steps);
  
  // Move motor
  for (long i = 0; i < absSteps; i++) {
    digitalWrite(STEP_PIN, HIGH);
    delayMicroseconds(1000);
    digitalWrite(STEP_PIN, LOW);
    delayMicroseconds(1000);
  }
}

void checkAlarms() {
  DateTime now = rtc.now();
  int currentDay = now.dayOfTheWeek(); // 0 = Sunday, 1 = Monday, etc.
  
  // Debug print current time
  Serial.print("Current time: ");
  Serial.print(now.day());
  Serial.print("/");
  Serial.print(now.month());
  Serial.print("/");
  Serial.print(now.year());
  Serial.print(" ");
  Serial.print(now.hour());
  Serial.print(":");
  if (now.minute() < 10) Serial.print("0");
  Serial.println(now.minute());
  
  // Check each alarm
  for (int i = 0; i < alarmCount; i++) {
    if (alarms[i].enabled && 
        alarms[i].hour == now.hour() && 
        alarms[i].minute == now.minute() &&
        (alarms[i].days & (1 << currentDay))) { // Check if alarm is set for current day
      
      Serial.print("Alarm triggered: ");
      Serial.print(alarms[i].hour);
      Serial.print(":");
      if (alarms[i].minute < 10) Serial.print("0");
      Serial.print(alarms[i].minute);
      Serial.print(" - Action: ");
      Serial.println(alarms[i].action == 0 ? "UP" : "DOWN");
      
      // Perform action
      if (alarms[i].action == 0) {
        moveBlindUp();
      } else {
        moveBlindDown();
      }
    }
  }
}

void setupWebServer() {
  // Root page
  server.on("/", HTTP_GET, handleRoot);
  
  // API endpoints
  server.on("/api/status", HTTP_GET, handleStatus);
  server.on("/api/moveto", HTTP_GET, handleMoveTo);
  server.on("/api/alarms", HTTP_GET, handleGetAlarms);
  server.on("/api/alarms", HTTP_POST, handleSetAlarms);
  server.on("/api/time", HTTP_GET, handleGetTime);
  server.on("/api/time", HTTP_POST, handleSetTime);
  server.on("/api/setup", HTTP_GET, handleSetupMode);
  server.on("/api/sync-ntp", HTTP_GET, handleSyncTimeNTP);
  
  // Add error handling
  server.onNotFound([]() {
    handleServerError();
    server.send(404, "text/plain", "Not found");
  });
  
  // Start server
  server.begin();
  Serial.println("HTTP server started");
}
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

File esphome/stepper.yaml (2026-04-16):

esphome:
  name: blinds

esp8266:
  board: nodemcuv2

logger:
api:
  password: ""
ota:
  - platform: esphome
    password: ""
wifi:
  ssid: "YOUR_WIFI_SSID"
  password: "YOUR_WIFI_PASSWORD"

  # Enable fallback hotspot (captive portal) in case wifi connection fails
  ap:
    ssid: "Blinds Fallback Hotspot"
    password: "YOUR_AP_PASSWORD"

# Stepper Motor Configuration
stepper:
  - platform: a4988
    id: my_stepper
    step_pin: D5
    dir_pin: D6
    max_speed: 250
    acceleration: 100
    deceleration: 100
    sleep_pin: GPIO16  # optional if you want to control SLP separately

# Control from Home Assistant
number:
  - platform: template
    name: "Stepper Target"
    min_value: -1000
    max_value: 1000
    step: 10
    set_action:
      then:
        - stepper.set_target:
            id: my_stepper
            target: !lambda 'return x;'

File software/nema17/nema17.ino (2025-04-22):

/*******************
 Created 1 May. 2020
  by Peter Chodyra
  www.candco.com.au
 *******************/

#include <ArduinoJson.h>

#include <ESP_EEPROM.h>
#include <ESP8266WiFi.h>          //https://github.com/esp8266/Arduino

//needed for library
#include <DNSServer.h>
#include <ESP8266WebServer.h>
#include <WiFiManager.h>          //https://github.com/tzapu/WiFiManager

//#define DEBUG

//IMPORTANT Make sure the D pins are correctly connected
#define dirPIN D5 
#define stepPIN D6
#define sleepPIN D7
#define hotPIN D8

// ------------------------------------------------------------------------
// ############################# Global Definitions #########################
// ------------------------------------------------------------------------

int MAXSteps = 0; //Global variable fo rthe maximum steps to open blinds = 100% open

//const int moveSteps = 200; //Steps to advance the motor at setup
const int stepsPerRevolution = 200; //this has been changed to 200 for the Nema14 with A4988 driver board
int movesLeft = 0; //This holds the current remaining percent of move to make, this will be used in main loop to prevent blocking behaviour of teh stepper function 
int target = 0; //Target percentage as received in url
int targetPercentage = 0;

//int advanceAmount = 1; //for non blocking stepper set the advance amount each itteration
int turningDirection = 0;
int stepSpeed = 1000;


bool moveDone = false;

//Stepper setup
const int clockwise = 1;
const int counterclockwise = 0;

// ------------------------------------------------------------------------
// ############################# EEPROM Definitions #########################
// ------------------------------------------------------------------------
int addr = 0; //EEPROM Address memory space for the current_position of the blinds
struct EEPROMStruct {
  int MAXsteps;
  int CURsteps;
  int CURpercent;
  int STEPSpercent;
  int Orientation;
} eepromVar;

// ------------------------------------------------------------------------
// ############################# HTML Definitions #########################
// ------------------------------------------------------------------------

const String HTMLheader = "<!DOCTYPE html><html><head>"\
"<link rel=\"stylesheet\" href=\"https://use.fontawesome.com/releases/v5.3.1/css/all.css\" integrity=\"sha384-mzrmE5qonljUremFsqc01SB46JvROS7bZs3IO2EmfFsd15uHvIt+Y8vEf7N7fWAU\" crossorigin=\"anonymous\">"\
"</head>"\
"<style>"\
" .koobee_wrap{   "\
"    width: 100%;"\
"    margin: 0 auto;"\
"    background-color: grey;}"\
" .koobee {"\
"padding:10px; margin:5px;}"\
"  .blue_top{"\
"    background: #4096ee;"\ 
"background: -moz-linear-gradient(top, #4096ee 0%, #60abf8 44%, #7abcff 100%); "\
"background: -webkit-linear-gradient(top, #4096ee 0%,#60abf8 44%,#7abcff 100%); "\
"background: linear-gradient(to bottom, #4096ee 0%,#60abf8 44%,#7abcff 100%);}"\
"  .blue {"\
"    background: #7abcff; "\
"background: -moz-linear-gradient(top, #7abcff 0%, #60abf8 44%, #4096ee 100%); "\
"background: -webkit-linear-gradient(top, #7abcff 0%,#60abf8 44%,#4096ee 100%); "\
"background: linear-gradient(to bottom, #7abcff 0%,#60abf8 44%,#4096ee 100%); }"\
"  .green {"\
"    background: #f8ffe8; "\
"background: -moz-linear-gradient(top, #f8ffe8 0%, #e3f5ab 33%, #b7df2d 100%); "\
"background: -webkit-linear-gradient(top, #f8ffe8 0%,#e3f5ab 33%,#b7df2d 100%); "\
"background: linear-gradient(to bottom, #f8ffe8 0%,#e3f5ab 33%,#b7df2d 100%); }"\
"  .lavender {"\
"    background: #c3d9ff; "\
"background: -moz-linear-gradient(top, #c3d9ff 0%, #b1c8ef 41%, #98b0d9 100%);"\ 
"background: -webkit-linear-gradient(top, #c3d9ff 0%,#b1c8ef 41%,#98b0d9 100%); "\
"background: linear-gradient(to bottom, #c3d9ff 0%,#b1c8ef 41%,#98b0d9 100%); }"\
"  .orange{"\
"    background: #ffa84c; "\
"background: -moz-linear-gradient(top, #ffa84c 0%, #ff7b0d 100%); "\
"background: -webkit-linear-gradient(top, #ffa84c 0%,#ff7b0d 100%); "\
"background: linear-gradient(to bottom, #ffa84c 0%,#ff7b0d 100%); }"\
" .red{"\
"background: #ff776b;"\
"background: -moz-linear-gradient(top, #ff776b 0%, #f25252 100%); "\
"background: -webkit-linear-gradient(top, #ff776b 0%,#f25252 100%);"\
"background: linear-gradient(to bottom, #ff776b 0%,#f25252 100%);};"\
"  .koobee h1 {font-family: Gotham, \"Helvetica Neue\", Helvetica, Arial, \"sans-serif\";}"\
"  .koobee p {font-family: Gotham, \"Helvetica Neue\", Helvetica, Arial, \"sans-serif\";font-size: 28px;}"\
"  .btnrow1{text-align: center;}"\
"  .btns{"\
"    text-align: center;"\
"    width: 100%}"\
"  .menu {padding: 5px;}"\
"  .menu a {color: black;"\
"  text-decoration: none;}"\
".koobee button2 {"\
"     width: 105px;"\
"    display: inline-block;"\
"    border: none;"\
"    padding: 1rem 2rem;"\
"    margin: 0;"\
"    text-decoration: none;"\
"    background: #0069ed;"\
"    color: #ffffff;"\
"    font-family: sans-serif;"\
"    font-size: 1rem;"\
"    line-height: 1;"\
"    cursor: pointer;"\
"    text-align: center;"\
"    transition: background 250ms ease-in-out, transform 150ms ease;"\
"    -webkit-appearance: none;"\
"    -moz-appearance: none;"\
"}"\
".koobee button2:hover,button:focus {background: #0053ba;}"\
".koobee button2:focus {outline: 1px solid #fff;outline-offset: -4px;}"\
".koobee button2:active {transform: scale(0.99);}"\
".koobee button {"\
"     width: 115px;"\
"-moz-box-shadow: 0px 10px 14px -7px #3e7327;"\
" -webkit-box-shadow: 0px 10px 14px -7px #3e7327;"\
"  box-shadow: 0px 10px 14px -7px #3e7327;"\
"  background-color:#77b55a;"\
"  -moz-border-radius:4px;"\
"  -webkit-border-radius:4px;"\
"  border-radius:4px;"\
"  border:1px solid #4b8f29;"\
"  display:inline-block;"\
"  cursor:pointer;"\
"  color:#ffffff;"\
"  font-family:Arial;"\
"  font-size:2em;"\
"  font-weight:bold;"\
"  padding:6px 12px;"\
"  margin-bottom: 40px;"\
"  text-decoration:none;"\
"  text-shadow:0px 1px 0px #5b8a3c;}"\
".koobee button:hover { background-color:#72b352;}"\
".koobee button:active {position:relative;top:1px;}"\
"  </style>"\
"<body><div class=\"koobee_wrap\">";

const String HTMLfooter = "</div></body></html>";

const String HTMLheading =" <div class=\"koobee blue_top\">"\
"      <h1 style=\"text-align: center;\">DIY SmartBlinds vNema<br>Control Panel</h1>"\
"  </div>";
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

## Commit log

2025-04-22 driver code working custom apporach
2025-04-22 added stuff
    [BoxBottom.stl, BoxTop-ButtonHole.stl, BoxTop.stl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]
2025-04-26 encoder and motor out of sync
2025-04-26 added limits for encoder
2025-05-16 new mechanical time fixes, need to investiage time drift
    [blinds_controller.ino]
2026-04-16 Add README and clean up repo for public presentation
    - Add comprehensive README.md with project overview, hardware details,
    wiring table, build instructions, API docs, and project structure
    - Remove hardcoded WiFi credentials from all source files and replace
    with placeholder values (blinds_controller.ino, blinds.yaml,
    stepper.yaml, stepper_blinds.yaml)
    - Remove stray root-level files (demo_step.ino, idk.ino)
    - Remove .DS_Store and Fusion Client Downloader.dmg
    - Expand .gitignore to cover macOS files, IDE configs, build artifacts,
    installers, and FreeCAD backups
    https://claude.ai/code/session_01BqwtTLTeqt9Qfu14j92jn2
    [blinds_controller.ino, demo_step.ino, stepper.yaml]
